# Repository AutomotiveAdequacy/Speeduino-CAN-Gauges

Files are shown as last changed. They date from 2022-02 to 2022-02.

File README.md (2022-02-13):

# Speeduino-CAN-Gauges
An analog stepper motor gauge cluster that gets data over serial from a speeduino ECU

 - AX1201728SG stepper drivers and X25.168 stepper motors
 - right now setup for 5 gauges
 - warning LED's on each gauge
 - LED Alternator excite that should work with most cars that normally use a incandescent bulb as an excite
 - Arduino Nano controlled
 - two spare analog inputs if wanted to have a button to control the 7-seg display, or analog input over CAN as a sensor for a speeduino

This is all a work in process, I worked through this pretty quick so there are a few areas that need refining but hopfully getting this out there allows people to pick and choose parts for their own projects.

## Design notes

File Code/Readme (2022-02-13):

You will need to enable serial communications in your speeduino, this is meant to be wired to the secondary serial port on the speeduino board, not the one that you connect tuner studio to.

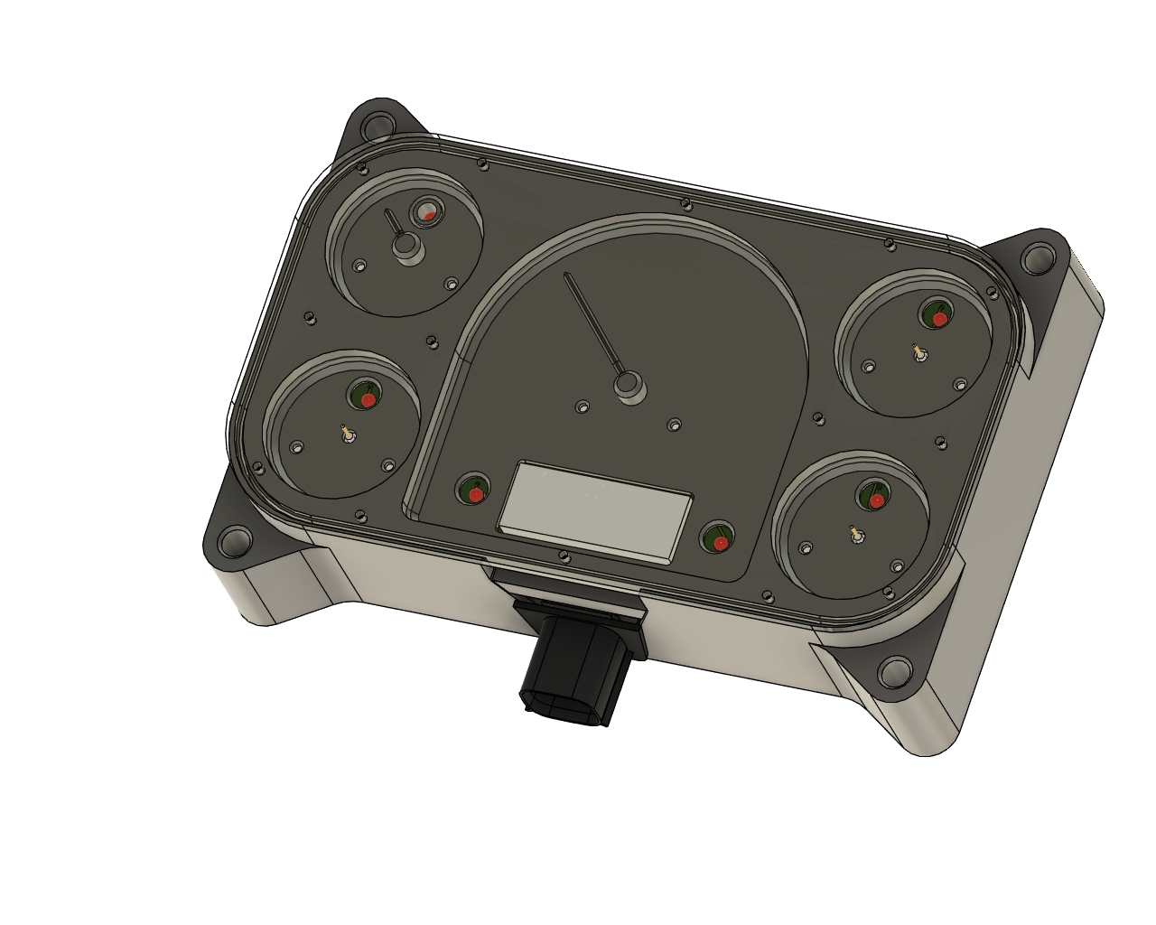
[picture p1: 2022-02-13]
Guage Cluster CAD.png

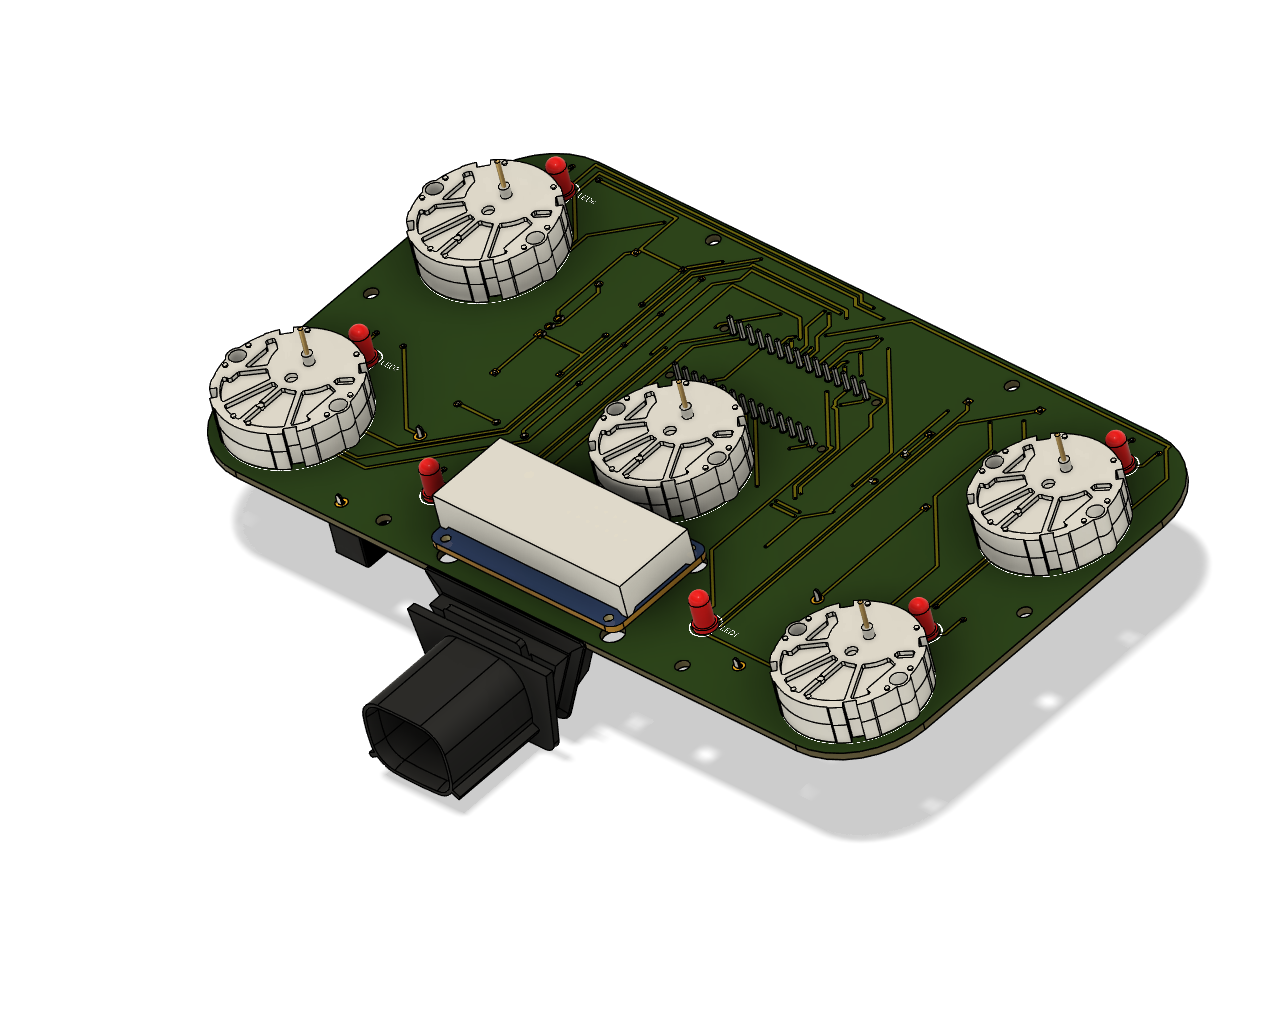
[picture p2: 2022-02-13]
PCB CAD.png

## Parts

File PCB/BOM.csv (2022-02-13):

 | Reference | Quantity | Value | Manufacturer_Name | Manufacturer_Part_Number | Footprint | URL | Digikey Part Number | Digikey BOM import
Alternator Excite | D1 | 1 | Diode - General purpose | Vishay | 1N914TAP | Diode_THT:D_DO-35_SOD27_P7.62mm_Horizontal | https://www.digikey.com.au/product-detail/en/vishay-general-semiconductor-diodes-division/1N914TAP/1N914TAPGICT-ND/8564478 | 1N914TAPGICT-ND | 6,1N914TAPGICT-ND
 | LED1,LED2,3,4,5,6 | 6 | RED 5MM |  |  |  |  | 160-1701-ND
 | R1 | 1 | 50Ω 5W |  |  |  |  | 25J50RE-ND
 | R2 | 1 | 500Ω 0.5W |  |  |  |  | CMF500HY-ND
Connector | J1 |  |  |  |  |  | https://www.molex.com/molex/products/part-detail/pcb_headers/0348300801
Arduino | U1
Voltage Reg | U3 | 1 |  |  | IC REGULATOR LDO LM2940-5.0 1A TO220 |  |  | LM2940T-5.0/NOPB
 | U2 | 1 | SURGE ABSORBER 14MM 22V 1000A ZNR |  |  |  |  | F6389-ND |  | Ordered Alternate Part F6414-ND
 | C1,C3 |  | 0.1uF 50V |  | C322C104K5R5TA |  |  | 399-4329-ND
 | C2 |  | 10uF 30V |  | T356G106K035AT |  |  | 399-3654-ND |  | Alternate PN 399-11372-1-ND‎
 | C4 |  | 47uF 10V |  | TAP476K006CCS |  |  | 478-4180-ND
 | D2 |  |  |  | MBR150G |  |  | MBR150GOS-ND
 | D3 |  |  |  | 1N5919BG |  |  | 1N5919BGOS-ND
Gauges | S1,S2,S3,S4,S5 |  |  |  | X27.168
 | U4, U5 |  |  |  | AX1201728SG
 | F1,F2 |  |  |  |  |  |  | 36-4527-ND
 | Fuse 2A (12v) |  |  |  |  |  | https://www.digikey.com/en/products/detail/bel-fuse-inc/5MF-2-R/1009036 | 507-1264-ND
 | Fuse 1A (5v) |  |  |  |  |  | https://www.digikey.com/en/products/detail/bel-fuse-inc/5MF-1-R/1009033 | 507-1261-ND
 | R3,4,5,6,7 |  | 500Ω 0.25W |  | CFM14JT220R |  | https://www.digikey.com/en/products/detail/stackpole-electronics-inc/CFM14JT220R/1742139 | S220QCT-ND
 | U6 |  |  |  |  |  | https://www.adafruit.com/product/1002
Chassis Connector | Connector | 33472-4806
 | Pin | 33012-2003

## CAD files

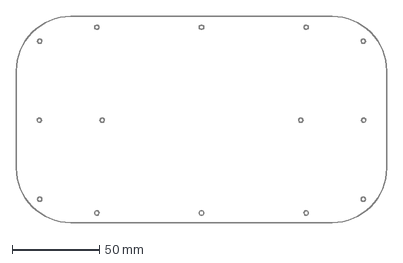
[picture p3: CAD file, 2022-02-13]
3d CAD/Acrylic Cover.dxf
212.6 x 118.3 mm

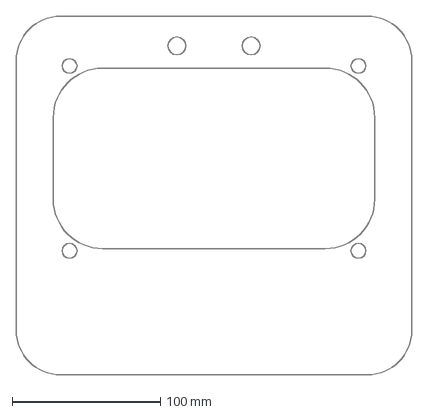
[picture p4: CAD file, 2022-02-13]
3d CAD/Sheetmetal Mount.dxf
266.6 x 241.6 mm

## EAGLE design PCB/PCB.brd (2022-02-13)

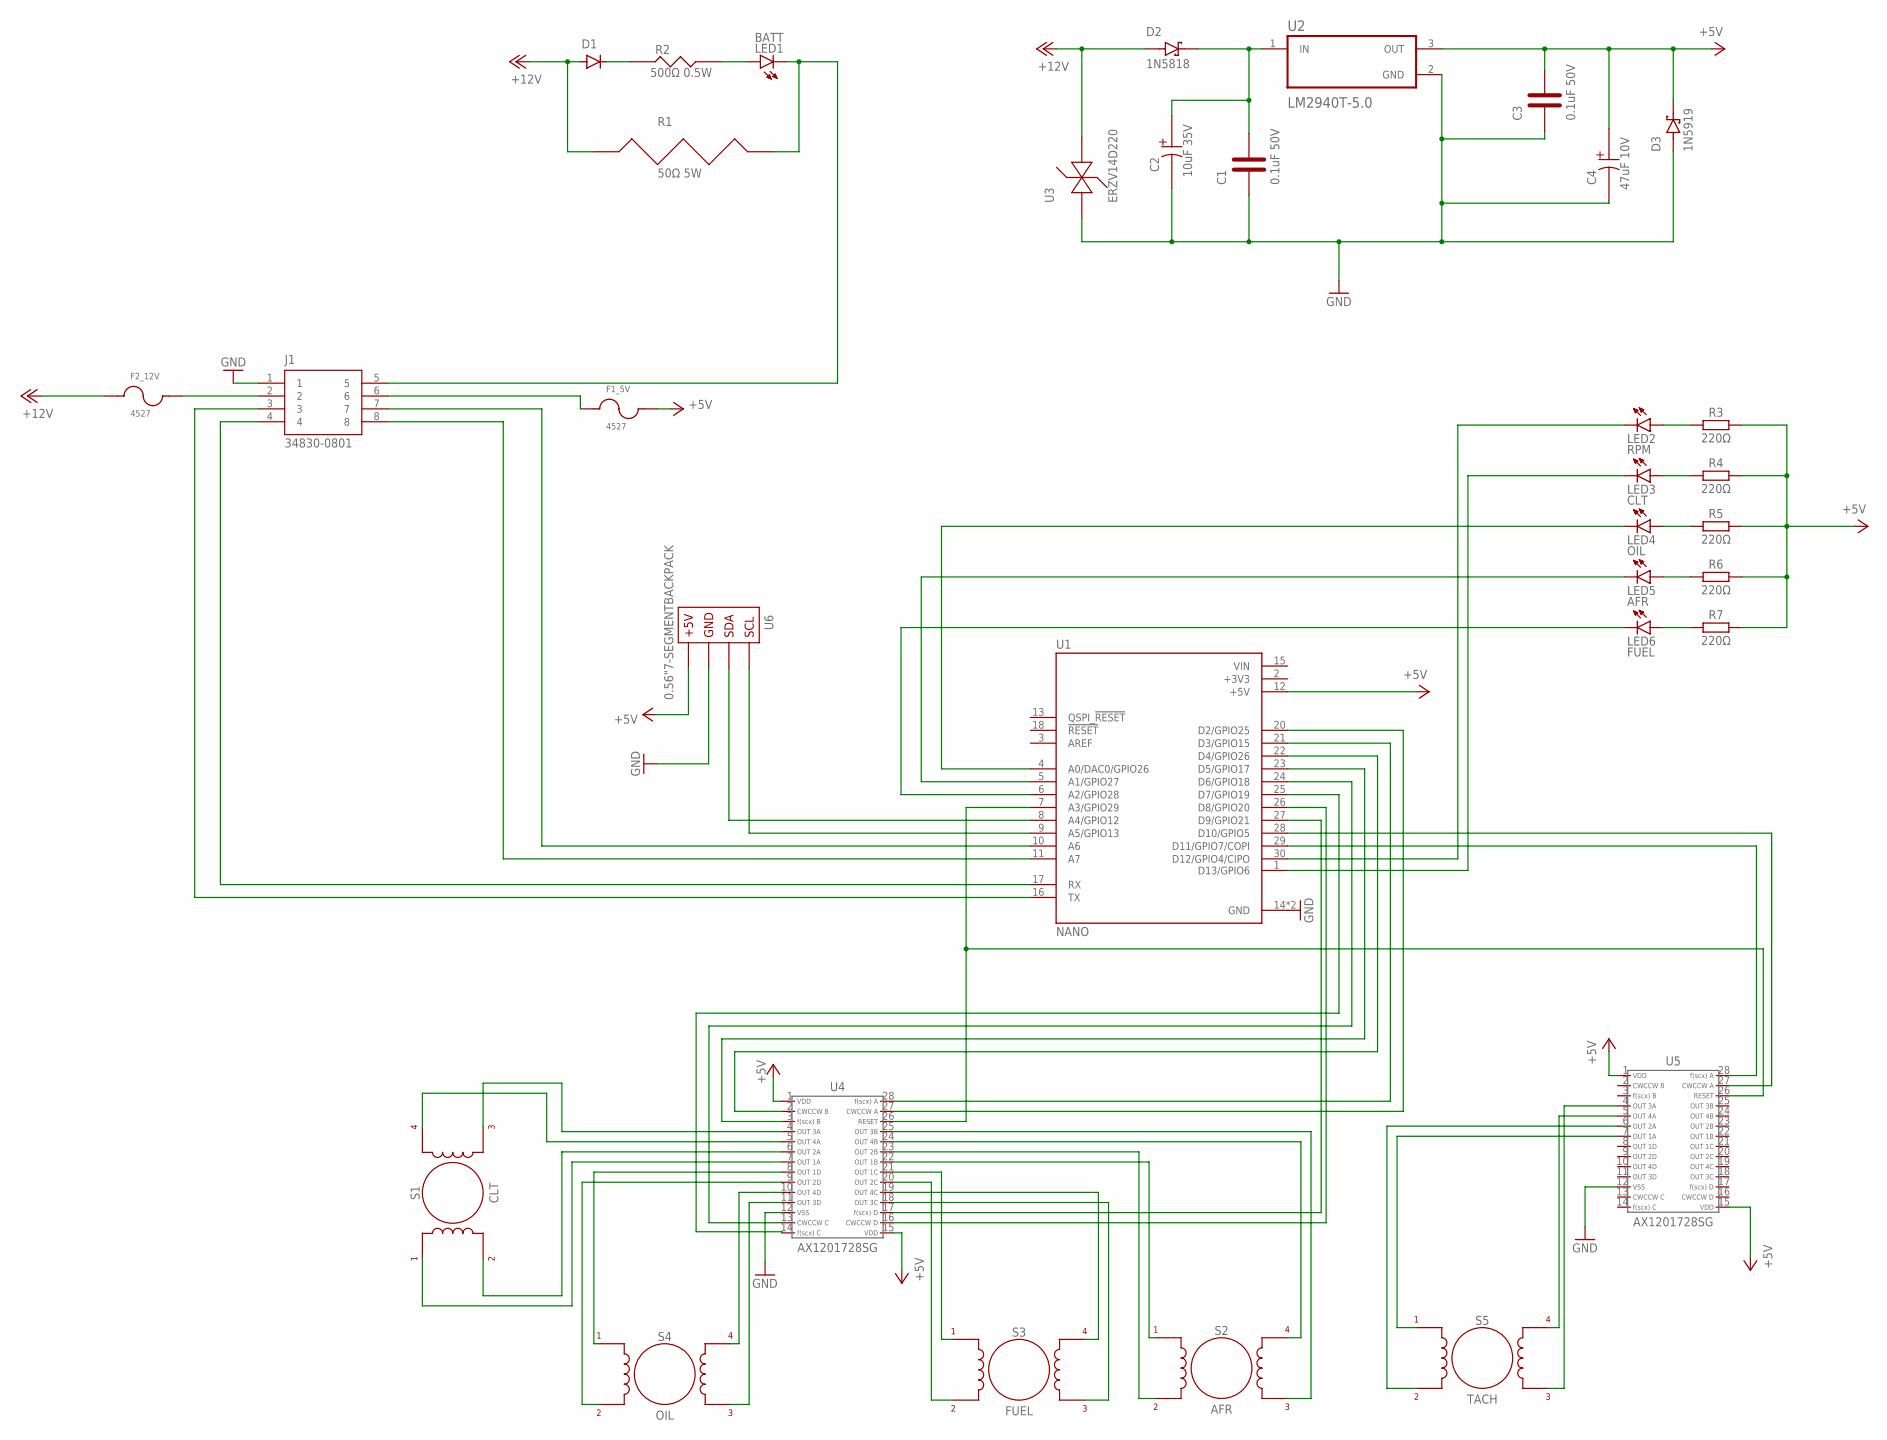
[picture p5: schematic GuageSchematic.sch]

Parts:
C1, C3: 0.1uF 50V; C322C104K5R5TA
C2: 10uF 35V; T356G106K035AT
C4: 47uF 10V; TAP476K006CCS
D1: 1N4004; DO-41
D2: 1N5818; DIOAD1036W78L520D271
D3: 1N5919; DIOAD1036W78L520D271
F1_5V, F2_12V: 4527
J1: 34830-0801; MOLEX_34830-0801
LED1: BATT; LED5MM
LED2: RPM; LED5MM
LED3: CLT; LED5MM
LED4: OIL; LED5MM
LED5: AFR; LED5MM
LED6: FUEL; LED5MM
R1: 50Ω 5W; 25J50RE
R2: 500Ω 0.5W; CMF55
R3, R4, R5, R6, R7: 220Ω; RESAD724W46L381D178B
S1: CLT; X27.168
S2: AFR; X27.168
S3: FUEL; X27.168
S4: OIL; X27.168
S5: TACH; X27.168
U1: NANO; MODULE_ABX00053
U2: LM2940T-5.0; TO254P1054X470X1955-3
U3: ERZV14D220
U4, U5: AX1201728SG
U6: 0.56"7-SEGMENTBACKPACK

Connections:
+3V3: U1.2 (+3V3)
+5V: C3.2, C4.1, D3.K, F1_5V.2, R3.2, R4.2, R5.2, R6.2, R7.2, U1.12 (+5V), U2.3 (OUT), U4.1, U4.15, U5.1, U5.15, U6.P$4
+12V: D1.A, D2.A, F2_12V.1, R1.1, U3.2
GND: C1.1, C2.2, C3.1, C4.2, D3.A, J1.1, U1.14 (GND), U1.19 (GND), U2.2 (GND), U3.1, U4.12, U5.12, U6.P$3
unnamed: J1.3, U1.16 (TX)
unnamed: J1.4, U1.17 (RX)
unnamed: J1.7, U1.10 (A6)
unnamed: J1.8, U1.11 (A7)
unnamed: D1.C, R2.1
unnamed: LED1.A, R2.2
unnamed: J1.5, LED1.K (C), R1.2
unnamed: C1.2, C2.1, D2.K, U2.1 (IN)
unnamed: F1_5V.1, J1.6
unnamed: F2_12V.2, J1.2
unnamed: U1.7 (A3/GPIO29), U4.26, U5.26
unnamed: U1.20 (D2/GPIO25), U4.27
unnamed: U1.21 (D3/GPIO15), U4.28
unnamed: U1.22 (D4/GPIO26), U4.2
unnamed: U1.23 (D5/GPIO17), U4.3
unnamed: U1.24 (D6/GPIO18), U4.13
unnamed: U1.25 (D7/GPIO19), U4.14
unnamed: U1.26 (D8/GPIO20), U4.16
unnamed: U1.27 (D9/GPIO21), U4.17
unnamed: U1.28 (D10/GPIO5), U5.27
unnamed: U1.29 (D11/GPIO7/COPI), U5.28
unnamed: LED2.A, R3.1
unnamed: LED3.A, R4.1
unnamed: LED4.A, R5.1
unnamed: LED5.A, R6.1
unnamed: LED6.A, R7.1
unnamed: LED2.K (C), U1.30 (D12/GPIO4/CIPO)
unnamed: LED3.K (C), U1.1 (D13/GPIO6)
unnamed: LED4.K (C), U1.4 (A0/DAC0/GPIO26)
unnamed: LED5.K (C), U1.5 (A1/GPIO27)
unnamed: LED6.K (C), U1.6 (A2/GPIO28)
unnamed: S1.P$1, U4.7
unnamed: S1.P$2, U4.6
unnamed: S1.P$3, U4.4
unnamed: S1.P$4, U4.5
unnamed: S5.P$1, U5.7
unnamed: S5.P$2, U5.6
unnamed: S5.P$3, U5.4
unnamed: S5.P$4, U5.5
unnamed: S4.P$1, U4.8
unnamed: S4.P$2, U4.9
unnamed: S4.P$3, U4.11
unnamed: S4.P$4, U4.10
unnamed: S3.P$3, U4.18
unnamed: S3.P$4, U4.19
unnamed: S3.P$2, U4.20
unnamed: S3.P$1, U4.21
unnamed: S2.P$1, U4.22
unnamed: S2.P$2, U4.23
unnamed: S2.P$4, U4.24
unnamed: S2.P$3, U4.25
unnamed: U1.8 (A4/GPIO12), U6.P$2
unnamed: U1.9 (A5/GPIO13), U6.P$1
VIN: U1.15 (VIN)

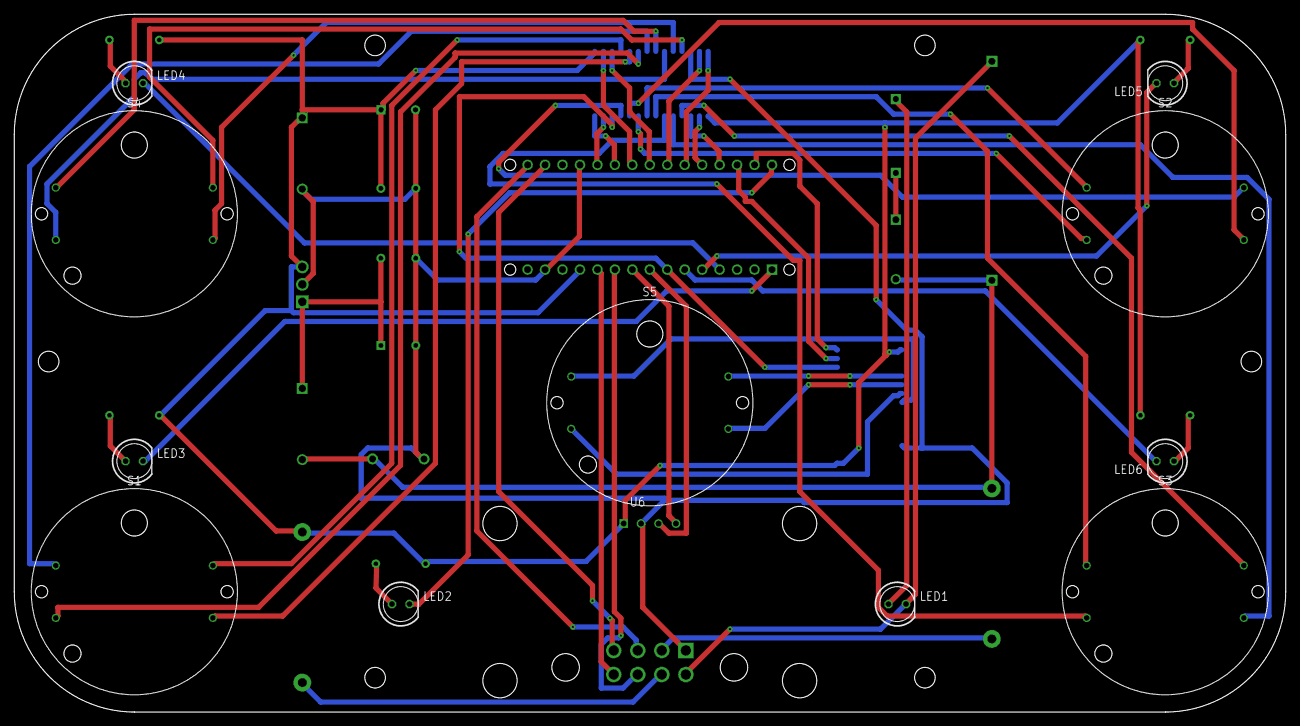
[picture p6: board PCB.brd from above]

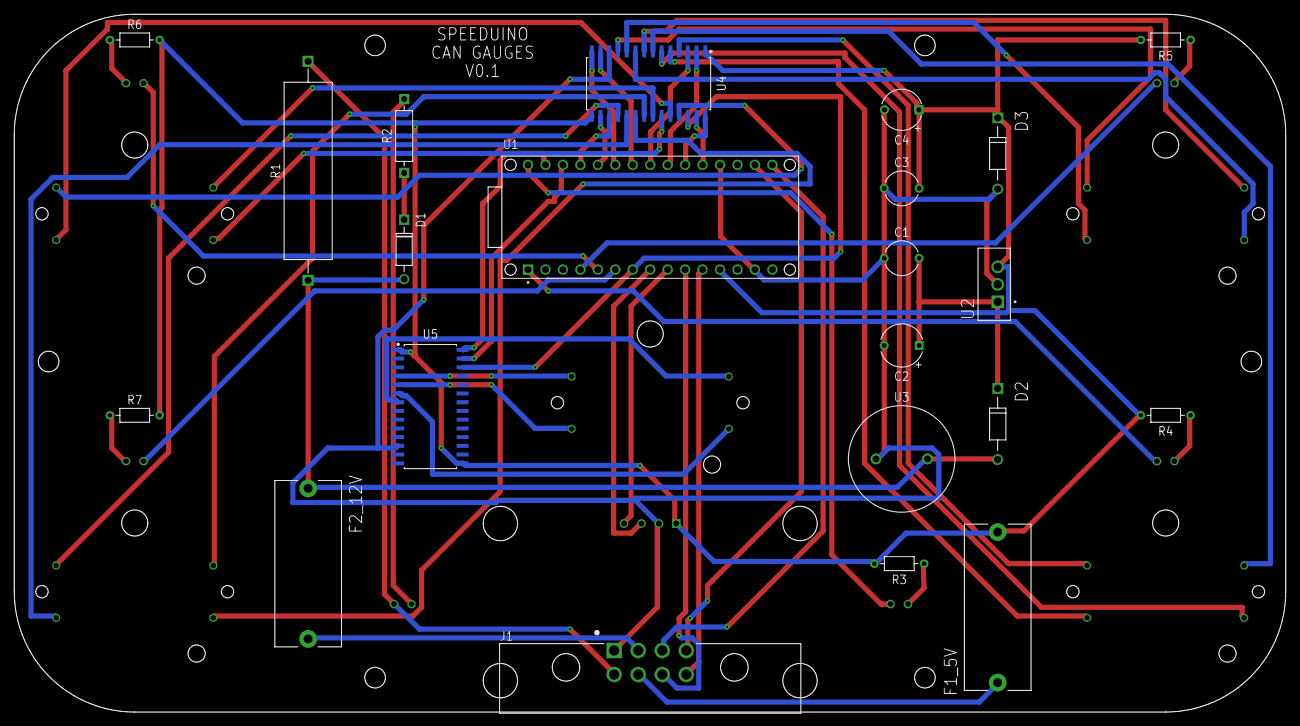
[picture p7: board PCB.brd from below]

Board: 2 copper layers, 185.0 x 101.5 mm, 34 parts (22 on the bottom side), 56 nets.

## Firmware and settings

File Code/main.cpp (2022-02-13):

#include <SPI.h>
#include <Wire.h>
#include <Arduino.h>
#include <SwitecX12.h>            //for stepper motors
#include <Adafruit_GFX.h>         //it looks like this is needed for i2c 7 seg
#include <Adafruit_LEDBackpack.h> //for segmented display
#include <SoftwareSerial.h>       //using software serial for debugging
#include <comms.h> //contains functions for speeduino serial data

// Board Constants
#define RESET 17
#define CLT_DIR 2
#define CLT_STEP 3
#define CLT_LED 13
#define OIL_DIR 8
#define OIL_STEP 9
#define OIL_LED 14
#define GAS_DIR 6
#define GAS_STEP 7
#define GAS_LED 16
#define AFR_DIR 4
#define AFR_STEP 5
#define AFR_LED 15
#define RPM_DIR 10
#define RPM_STEP 11
#define RPM_LED 12
#define AUX1_IN 20 // A6
#define AUX2_IN 21 // A7
#define SDA 18
#define SCL 19

// program constants
const int STEPS = 315 * 12;
#define CLT_low 150
#define CLT_high 250
#define CLT_warn_low 100
#define CLT_warn_high 220

#define OIL_low 0
#define OIL_high 1000
#define OIL_warn_low 50
#define OIL_warn_high 1000

#define GAS_low 0
#define GAS_high 100
#define GAS_warn_low 25
#define GAS_warn_high 110 //essentially never

#define AFR_low 1000
#define AFR_high 2000
#define AFR_warn_low 1000
#define AFR_warn_high 1700

#define RPM_low 0
#define RPM_high 8000
#define RPM_warn_low 200
#define RPM_warn_high 7000

// global variables
int AFR = AFR_low;
int GAS = GAS_low;
int CLT = CLT_low;
int RPM = RPM_low;
int OIL = OIL_low;
int BAT = 0;

// define Motors
SwitecX12 motor_CLT(STEPS, CLT_STEP, CLT_DIR);
SwitecX12 motor_OIL(STEPS, OIL_STEP, OIL_DIR);
SwitecX12 motor_GAS(STEPS, GAS_STEP, GAS_DIR);
SwitecX12 motor_AFR(STEPS, AFR_STEP, AFR_DIR);
SwitecX12 motor_RPM(STEPS, RPM_STEP, RPM_DIR);

// Seven Segment Display Setup
Adafruit_7segment speedo = Adafruit_7segment();

// Functions
//SoftwareSerial SoftSerial(AUX1_IN, AUX2_IN); // RX, TX (7 & 8 on chassis connector)
//#define  SoftSerial //choose if speeduino is on software or hardware port
#define SerialSpeeduino Serial //choose if debug is on software or hardware port
void startupSerial(){
  SerialSpeeduino.begin(115200);
  //SerialDebug.begin(115200);
}

void allMotorReset(){

  motor_CLT.setPosition(STEPS);
  motor_OIL.setPosition(STEPS);
  motor_GAS.setPosition(STEPS);
  motor_AFR.setPosition(STEPS);
  motor_RPM.setPosition(STEPS);

  motor_CLT.update();
  motor_OIL.update();
  motor_GAS.update();
  motor_AFR.update();
  motor_RPM.update();

  while(!motor_CLT.stopped && !motor_OIL.stopped && !motor_GAS.stopped && !motor_AFR.stopped && !motor_RPM.stopped){
    motor_CLT.update();
    motor_OIL.update();
    motor_GAS.update();
    motor_AFR.update();
    motor_RPM.update();
  }

  motor_CLT.setPosition(0);
  motor_OIL.setPosition(0);
  motor_GAS.setPosition(0);
  motor_AFR.setPosition(0);
  motor_RPM.setPosition(0);
  
  motor_CLT.update();
  motor_OIL.update();
  motor_GAS.update();
  motor_AFR.update();
  motor_RPM.update();

  while(!motor_CLT.stopped && !motor_OIL.stopped && !motor_GAS.stopped && !motor_AFR.stopped && !motor_RPM.stopped){
    motor_CLT.update();
    motor_OIL.update();
    motor_GAS.update();
    motor_AFR.update();
    motor_RPM.update();
  }
}

void updateMotors()
{
  int temp = map(CLT, CLT_low, CLT_high, 0, STEPS);
  temp = constrain(temp,0,STEPS);
  motor_CLT.setPosition(temp);
  motor_CLT.update();

  temp = map(OIL, OIL_low, OIL_high, 0, STEPS);
  temp = constrain(temp,0,STEPS);
  motor_OIL.setPosition(temp);
  motor_OIL.update();

  temp = map(GAS, GAS_low, GAS_high, 0, STEPS);
  temp = constrain(temp,0,STEPS);
  motor_GAS.setPosition(temp);
  motor_GAS.update();

  temp = map(AFR, AFR_low, AFR_high, 0, STEPS);
  temp = constrain(temp,0,STEPS);
  motor_AFR.setPosition(temp);
  motor_AFR.update();

  temp = map(RPM, RPM_low, RPM_high, 0, STEPS);
  temp = constrain(temp,0,STEPS);
  motor_RPM.setPosition(temp);
  motor_RPM.update();
}

/*commented out section for testing values instead of reading from Serial
bool CLTup = true; //global values for test values function
bool OILup = true;
bool RPMup = true;
bool AFRup = true;
bool GASup = true;
void testValues()
{
  // test sweep
  if (CLT == CLT_high){CLTup = false;}
  else if (CLT == CLT_low){CLTup = true;}
  if (CLTup){CLT++;}
  else{CLT--;}

  if (OIL == OIL_high){OILup = false;}
  else if (OIL == OIL_low){OILup = true;}
  if (OILup){OIL++;}
  else{OIL--;}

  if (AFR == AFR_high){AFRup = false;}
  else if (AFR == AFR_low){AFRup = true;}
  if (AFRup){AFR=AFR + .1;}
  else{AFR = AFR - .1;}

  if (GAS == GAS_high){GASup = false;}
  else if (GAS == GAS_low){GASup = true;}
  if (GASup){GAS++;}
  else{GAS--;}

  if (RPM == RPM_high){RPMup = false;}
  else if (RPM == RPM_low){RPMup = true;}
  if (RPMup){RPM++;}
  else{RPM--;}
}
*/

bool warnCheck(int VAR, int VAR_low, int VAR_high)
{
  bool result = true;
  if (VAR <= VAR_low)
  {
    result = true;
  }
  else if (VAR >= VAR_high)
  {
    result = true;
  }
  else
  {
    result = false;
  }
  return result;
}

void warnLED()
{
  if (warnCheck(CLT, CLT_warn_low, CLT_warn_high))
  {
    digitalWrite(CLT_LED, LOW);
  }
  else
  {
    digitalWrite(CLT_LED, HIGH);
  }

  if (warnCheck(OIL, OIL_warn_low, OIL_warn_high))
  {
    digitalWrite(OIL_LED, LOW);
  }
  else
  {
    digitalWrite(OIL_LED, HIGH);
  }

  if (warnCheck(RPM, RPM_warn_low, RPM_warn_high))
  {
    digitalWrite(RPM_LED, LOW);
  }
  else
  {
    digitalWrite(RPM_LED, HIGH);
  }

  if (warnCheck(GAS, GAS_warn_low, GAS_warn_high))
  {
    digitalWrite(GAS_LED, LOW);
  }
  else
  {
    digitalWrite(GAS_LED, HIGH);
  }

  if (warnCheck(AFR, AFR_warn_low, AFR_warn_high))
  {
    digitalWrite(AFR_LED, LOW);
  }
  else
  {
    digitalWrite(AFR_LED, HIGH);
  }
}

void readSpeeduino()
{
  // serial operation, frequency based request
  static uint32_t lastUpdate = millis();
  if (millis() - lastUpdate > 100) //too quick and it will mess up stepper control
  {
    requestData(50);
    lastUpdate = millis();
  }

  // get refresh rate
  static uint32_t lastRefresh = millis();
  uint16_t refreshRate = 1000 / (millis() - lastRefresh); //not currently using but here just incase
  lastRefresh = millis();

  //pull data, use getword for ones with two bytes and getbyte for just bytes
  RPM = getWord(14); //engine speed in RPM
  CLT = getByte(7)-40;  //coolant in deg C, subtracting coolant offset to allow neg value
  CLT = (1.8*CLT)+32; //convert to deg F
  OIL = getWord(41); //oil pressure, from AUX 0
  OIL = map(OIL,0,1023,-30,1030); //convert OIL into 0-100psi, x10 for better resolution
  OIL = constrain(OIL,0,1000);
  AFR = getByte(10); //AFR based on calibration range 9-19 in my case
  AFR = map(AFR,0,255,900,1900); //convert AFR into 9-19 based on calibration for 0-5v, also x100 to get decimal place into long variable
  AFR = constrain(AFR,900,1900);
  GAS = getWord(43); //fuel level AUX input 1, coming in 0-1023 range
  GAS = map(GAS,49,532,100,0); //convert gas into 0-100% based on calibration data
  GAS = constrain(GAS,0,100);
  BAT = getByte(9); //battery voltage * 10

  //addresses that aren't used
  //getWord(4); MAP
  //getByte(9); Battery voltage
  //getWord(100); Speed in KPH
  //(int8_t)getByte(23); ignition advance
  //(int8_t)getByte(3); injector dwell
}

void setupLEDs(){
  //Setup Pins
  pinMode(CLT_LED, OUTPUT);
  pinMode(OIL_LED, OUTPUT);
  pinMode(AFR_LED, OUTPUT);
  pinMode(GAS_LED, OUTPUT);
  pinMode(RPM_LED, OUTPUT);
  // flash LEDs
  digitalWrite(CLT_LED, LOW);
  digitalWrite(OIL_LED, LOW);
  digitalWrite(AFR_LED, LOW);
  digitalWrite(GAS_LED, LOW);
  digitalWrite(RPM_LED, LOW);
  // startup 7 seg display
  speedo.begin(0x70);
  speedo.print("8888");
  speedo.writeDisplay();
  //delay(500);
  digitalWrite(CLT_LED, HIGH);
  digitalWrite(OIL_LED, HIGH);
  digitalWrite(AFR_LED, HIGH);
  digitalWrite(GAS_LED, HIGH);
  digitalWrite(RPM_LED, HIGH);
  speedo.clear();
  speedo.writeDisplay();
}

void setup()
{
  digitalWrite(LED_BUILTIN,HIGH);
  setupLEDs();
  startupSerial();
  digitalWrite(RESET, HIGH); // turn off reset of stepper chip
  speedo.print(8008);
  speedo.writeDisplay();
  allMotorReset();
  
}
const int freq = 500; //display update time in milliseconds
unsigned long prevUpdate = 0;
void loop()
{
  //testValues();
  readSpeeduino();
  warnLED();
  updateMotors();

//only update the display at lower frequency, too high frequency and it messes up the steppers
  if(freq < (millis()-prevUpdate)){
    speedo.print(BAT/10.0);
    speedo.writeDisplay();
    prevUpdate = millis();
  }
}

/*Reference of everything sent with 'n' command
fullStatus[0] = currentStatus.secl; //secl is simply a counter that increments each second. Used to track unexpected resets (Which will reset this count to 0)
  fullStatus[1] = currentStatus.status1; //status1 Bitfield, inj1Status(0), inj2Status(1), inj3Status(2), inj4Status(3), DFCOOn(4), boostCutFuel(5), toothLog1Ready(6), toothLog2Ready(7)
  fullStatus[2] = currentStatus.engine; //Engine Status Bitfield, running(0), crank(1), ase(2), warmup(3), tpsaccaen(4), tpsacden(5), mapaccaen(6), mapaccden(7)
  fullStatus[3] = (byte)(divu100(currentStatus.dwell)); //Dwell in ms * 10
  fullStatus[4] = lowByte(currentStatus.MAP); //2 bytes for MAP
  fullStatus[5] = highByte(currentStatus.MAP);
  fullStatus[6] = (byte)(currentStatus.IAT + CALIBRATION_TEMPERATURE_OFFSET); //mat
  fullStatus[7] = (byte)(currentStatus.coolant + CALIBRATION_TEMPERATURE_OFFSET); //Coolant ADC
  fullStatus[8] = currentStatus.batCorrection; //Battery voltage correction (%)
  fullStatus[9] = currentStatus.battery10; //battery voltage
  fullStatus[10] = currentStatus.O2; //O2
  fullStatus[11] = currentStatus.egoCorrection; //Exhaust gas correction (%)
  fullStatus[12] = currentStatus.iatCorrection; //Air temperature Correction (%)
  fullStatus[13] = currentStatus.wueCorrection; //Warmup enrichment (%)
  fullStatus[14] = lowByte(currentStatus.RPM); //rpm HB
  fullStatus[15] = highByte(currentStatus.RPM); //rpm LB
  fullStatus[16] = currentStatus.AEamount; //acceleration enrichment (%)
  fullStatus[17] = currentStatus.corrections; //Total GammaE (%)
  fullStatus[18] = currentStatus.VE; //Current VE 1 (%)
  fullStatus[19] = currentStatus.afrTarget;
  fullStatus[20] = lowByte(currentStatus.PW1); //Pulsewidth 1 multiplied by 10 in ms. Have to convert from uS to mS.
  fullStatus[21] = highByte(currentStatus.PW1); //Pulsewidth 1 multiplied by 10 in ms. Have to convert from uS to mS.
  fullStatus[22] = currentStatus.tpsDOT; //TPS DOT
  fullStatus[23] = currentStatus.advance;
  fullStatus[24] = currentStatus.TPS; // TPS (0% to 100%)
  //Need to split the int loopsPerSecond value into 2 bytes
  fullStatus[25] = lowByte(currentStatus.loopsPerSecond);
  fullStatus[26] = highByte(currentStatus.loopsPerSecond);

  //The following can be used to show the amount of free memory
  currentStatus.freeRAM = freeRam();
  fullStatus[27] = lowByte(currentStatus.freeRAM); //(byte)((currentStatus.loopsPerSecond >> 8) & 0xFF);
  fullStatus[28] = highByte(currentStatus.freeRAM);

  fullStatus[29] = (byte)(currentStatus.boostTarget >> 1); //Divide boost target by 2 to fit in a byte
  fullStatus[30] = (byte)(currentStatus.boostDuty / 100);
  fullStatus[31] = currentStatus.spark; //Spark related bitfield, launchHard(0), launchSoft(1), hardLimitOn(2), softLimitOn(3), boostCutSpark(4), error(5), idleControlOn(6), sync(7)

  //rpmDOT must be sent as a signed integer
  fullStatus[32] = lowByte(currentStatus.rpmDOT);
  fullStatus[33] = highByte(currentStatus.rpmDOT);

  fullStatus[34] = currentStatus.ethanolPct; //Flex sensor value (or 0 if not used)
  fullStatus[35] = currentStatus.flexCorrection; //Flex fuel correction (% above or below 100)
  fullStatus[36] = currentStatus.flexIgnCorrection; //Ignition correction (Increased degrees of advance) for flex fuel

  fullStatus[37] = currentStatus.idleLoad;
  fullStatus[38] = currentStatus.testOutputs; // testEnabled(0), testActive(1)

  fullStatus[39] = currentStatus.O2_2; //O2
  fullStatus[40] = currentStatus.baro; //Barometer value

  fullStatus[41] = lowByte(currentStatus.canin[0]);
  fullStatus[42] = highByte(currentStatus.canin[0]);
  fullStatus[43] = lowByte(currentStatus.canin[1]);
  fullStatus[44] = highByte(currentStatus.canin[1]);
  fullStatus[45] = lowByte(currentStatus.canin[2]);
  fullStatus[46] = highByte(currentStatus.canin[2]);
  fullStatus[47] = lowByte(currentStatus.canin[3]);
  fullStatus[48] = highByte(currentStatus.canin[3]);
  fullStatus[49] = lowByte(currentStatus.canin[4]);
  fullStatus[50] = highByte(currentStatus.canin[4]);
  fullStatus[51] = lowByte(currentStatus.canin[5]);
  fullStatus[52] = highByte(currentStatus.canin[5]);
  fullStatus[53] = lowByte(currentStatus.canin[6]);
  fullStatus[54] = highByte(currentStatus.canin[6]);
  fullStatus[55] = lowByte(currentStatus.canin[7]);
  fullStatus[56] = highByte(currentStatus.canin[7]);
  fullStatus[57] = lowByte(currentStatus.canin[8]);
  fullStatus[58] = highByte(currentStatus.canin[8]);
  fullStatus[59] = lowByte(currentStatus.canin[9]);
  fullStatus[60] = highByte(currentStatus.canin[9]);
  fullStatus[61] = lowByte(currentStatus.canin[10]);
  fullStatus[62] = highByte(currentStatus.canin[10]);
  fullStatus[63] = lowByte(currentStatus.canin[11]);
  fullStatus[64] = highByte(currentStatus.canin[11]);
  fullStatus[65] = lowByte(currentStatus.canin[12]);
  fullStatus[66] = highByte(currentStatus.canin[12]);
  fullStatus[67] = lowByte(currentStatus.canin[13]);
  fullStatus[68] = highByte(currentStatus.canin[13]);
  fullStatus[69] = lowByte(currentStatus.canin[14]);
  fullStatus[70] = highByte(currentStatus.canin[14]);
  fullStatus[71] = lowByte(currentStatus.canin[15]);
  fullStatus[72] = highByte(currentStatus.canin[15]);

  fullStatus[73] = currentStatus.tpsADC;
  fullStatus[74] = getNextError(); // errorNum (0:1), currentError(2:7)

  fullStatus[75] = currentStatus.launchCorrection;
  fullStatus[76] = lowByte(currentStatus.PW2); //Pulsewidth 2 multiplied by 10 in ms. Have to convert from uS to mS.
  fullStatus[77] = highByte(currentStatus.PW2); //Pulsewidth 2 multiplied by 10 in ms. Have to convert from uS to mS.
  fullStatus[78] = lowByte(currentStatus.PW3); //Pulsewidth 3 multiplied by 10 in ms. Have to convert from uS to mS.
  fullStatus[79] = highByte(currentStatus.PW3); //Pulsewidth 3 multiplied by 10 in ms. Have to convert from uS to mS.
  fullStatus[80] = lowByte(currentStatus.PW4); //Pulsewidth 4 multiplied by 10 in ms. Have to convert from uS to mS.
  fullStatus[81] = highByte(currentStatus.PW4); //Pulsewidth 4 multiplied by 10 in ms. Have to convert from uS to mS.

  fullStatus[82] = currentStatus.status3; // resentLockOn(0), nitrousOn(1), fuel2Active(2), vssRefresh(3), halfSync(4), nSquirts(6:7)
  fullStatus[83] = currentStatus.engineProtectStatus; //RPM(0), MAP(1), OIL(2), AFR(3), Unused(4:7)
  fullStatus[84] = lowByte(currentStatus.fuelLoad);
  fullStatus[85] = highByte(currentStatus.fuelLoad);
  fullStatus[86] = lowByte(currentStatus.ignLoad);
  fullStatus[87] = highByte(currentStatus.ignLoad);
  fullStatus[88] = lowByte(currentStatus.injAngle); 
  fullStatus[89] = highByte(currentStatus.injAngle); 
  fullStatus[90] = currentStatus.idleDuty;
  fullStatus[91] = currentStatus.CLIdleTarget; //closed loop idle target
  fullStatus[92] = currentStatus.mapDOT; //rate of change of the map 
  fullStatus[93] = (int8_t)currentStatus.vvt1Angle;
  fullStatus[94] = currentStatus.vvt1TargetAngle;
  fullStatus[95] = currentStatus.vvt1Duty;
  fullStatus[96] = lowByte(currentStatus.flexBoostCorrection);
  fullStatus[97] = highByte(currentStatus.flexBoostCorrection);
  fullStatus[98] = currentStatus.baroCorrection;
  fullStatus[99] = currentStatus.ASEValue; //Current ASE (%)
  fullStatus[100] = lowByte(currentStatus.vss); //speed reading from the speed sensor
  fullStatus[101] = highByte(currentStatus.vss);
  fullStatus[102] = currentStatus.gear; 
  fullStatus[103] = currentStatus.fuelPressure;
  fullStatus[104] = currentStatus.oilPressure;
  fullStatus[105] = currentStatus.wmiPW;
  fullStatus[106] = currentStatus.status4; // wmiEmptyBit(0), vvt1Error(1), vvt2Error(2), fanStatus(3), UnusedBits(4:7)
  fullStatus[107] = (int8_t)currentStatus.vvt2Angle;
  fullStatus[108] = currentStatus.vvt2TargetAngle;
  fullStatus[109] = currentStatus.vvt2Duty;
  fullStatus[110] = currentStatus.outputsStatus;
  fullStatus[111] = (byte)(currentStatus.fuelTemp + CALIBRATION_TEMPERATURE_OFFSET); //Fuel temperature from flex sensor
  fullStatus[112] = currentStatus.fuelTempCorrection; //Fuel temperature Correction (%)
  fullStatus[113] = currentStatus.VE1; //VE 1 (%)
  fullStatus[114] = currentStatus.VE2; //VE 2 (%)
  fullStatus[115] = currentStatus.advance1; //advance 1 
  fullStatus[116] = currentStatus.advance2; //advance 2 
  fullStatus[117] = currentStatus.nitrous_status;
  fullStatus[118] = currentStatus.TS_SD_Status; //SD card status
  fullStatus[119] = lowByte(currentStatus.EMAP); //2 bytes for EMAP
  fullStatus[120] = highByte(currentStatus.EMAP);
  fullStatus[121] = currentStatus.fanDuty;

*/

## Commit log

2022-02-13 Create CAD Readme
2022-02-13 Create BOM
